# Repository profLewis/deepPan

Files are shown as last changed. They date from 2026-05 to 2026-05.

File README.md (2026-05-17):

# deepPan

3D printable tenor steel pan with section generator, note pads, and interactive sound design tools.

**Live site:** [proflewis.github.io/deepPan](https://proflewis.github.io/deepPan/)



## Project Overview

This project creates a **3D printable tenor steel pan** from a 3D scanned model. The pan is split into printable sections with individually mountable note pads, enabling replacement of damaged notes, experimentation with materials and tuning, and educational exploration of steel pan acoustics.

## Quick build (recreate the DEFINITIVE model from scratch)

The committed model in `pipeline_output/` is the **definitive build**. The
build pipeline below regenerates it byte-for-byte from `data/Tenor Pan only.obj`.

```bash
./build_from_scratch.sh         # full regenerate (~90 min)
python3 test_pipeline.py        # quick checksum check against committed manifest
python3 test_pipeline.py --full # full byte-for-byte regenerate-and-compare
```

The pipeline runs 14 stages:

1. Extract groove surfaces from source bowl
2. Solidify grooves (5 mm extrusion)
3. Generate 29 notepad meshes (no screw holes)
4. Build pan body (groove faces kept in body)
5. Extend outer-ring pad-hole boundaries
6. Thicken body to 5 mm solid
7. Generate per-pad groove-replacement ellipsoids
8. Merge body with central+inner ellipsoids
9. Voxel-remesh + pads + outer grooves + debris strip → `pan_printable.stl`
10. Split body into 7 printable pieces (truncate at Z=−122, solidify drum wall,
    build strut wedges with joinery)
11. Generate plug.stl (4 × 18 mm alignment peg)
12. Generate full bottom plate + split into 6 P1S-printable sectors
13. Generate Bambu P1S `.3mf` build plates (14 files)
14. Generate multi-object assembly view (no outer sleeves, per-pad mounts)

`pipeline_output/MANIFEST.sha256` records the SHA-256 of every committed
output; `test_pipeline.py` compares regenerated files against it (and removes
the redundant regenerated copies on a clean match).

## Printable parts and 3MF files

The full printable assembly is **14 files** ready to print on a Bambu P1S
(256 × 256 × 256 build volume):

| File | Qty | Notes |
|---|---|---|
| `pipeline_output/3mf/pan_central_half_0.3mf` and `_half_1.3mf` | 2 | Central bowl sliced in half at X=0. Each printed FLAT-CUT-FACE DOWN. 3 dowel-pin holes in tabs hanging from the bowl underside at the cut face — mated with 3 plugs from `small_parts_plugs.3mf`. Each half retains 3 of the 6 underside pegs that slot into the wedge tops. |
| `pipeline_output/3mf/pan_outer_0.3mf` … `pan_outer_5.3mf` | 6 | 60° outer sectors. Each has 2 half-wedges on its tangential edges (with horizontal-peg channels + central-peg receiver + base-screw tap holes) |
| `pipeline_output/3mf/bottom_plate_sector_0.3mf` … `_5.3mf` | 6 | Pie sectors of the bottom plate. Each has perimeter screws into the drum skirt + 2 wedge-screw clearance holes |
| `pipeline_output/3mf/small_parts_plugs.3mf` | 1 (= 12 plugs) | 12 horizontal alignment pegs — print all on one plate |

**Joinery** (no visible screw holes on the outside):

- **Adjacent outer pieces** → 2 horizontal pegs at each strut plane (R=130 + R=200), tangential axis, pushed in from the cavity side
- **Central piece** → 6 pegs baked onto its underside drop into receiver holes carved in the wedge tab tops
- **Bottom plate → wedges** → 12 M4 screws from below the plate, countersunk on the plate's underside
- **Bottom plate → drum skirt** → 8 M4 perimeter screws

## Inspecting the assembly

Open `pipeline_output/assembly_view_with_plugs.obj` in Blender — 49 separately
labelled objects (7 pan pieces + bottom plate + 12 horizontal pegs + 12 outer
mount bases + 17 central/inner push-caps). Each can be toggled on/off
independently to inspect any sub-system.

## Tenor Pan Layout

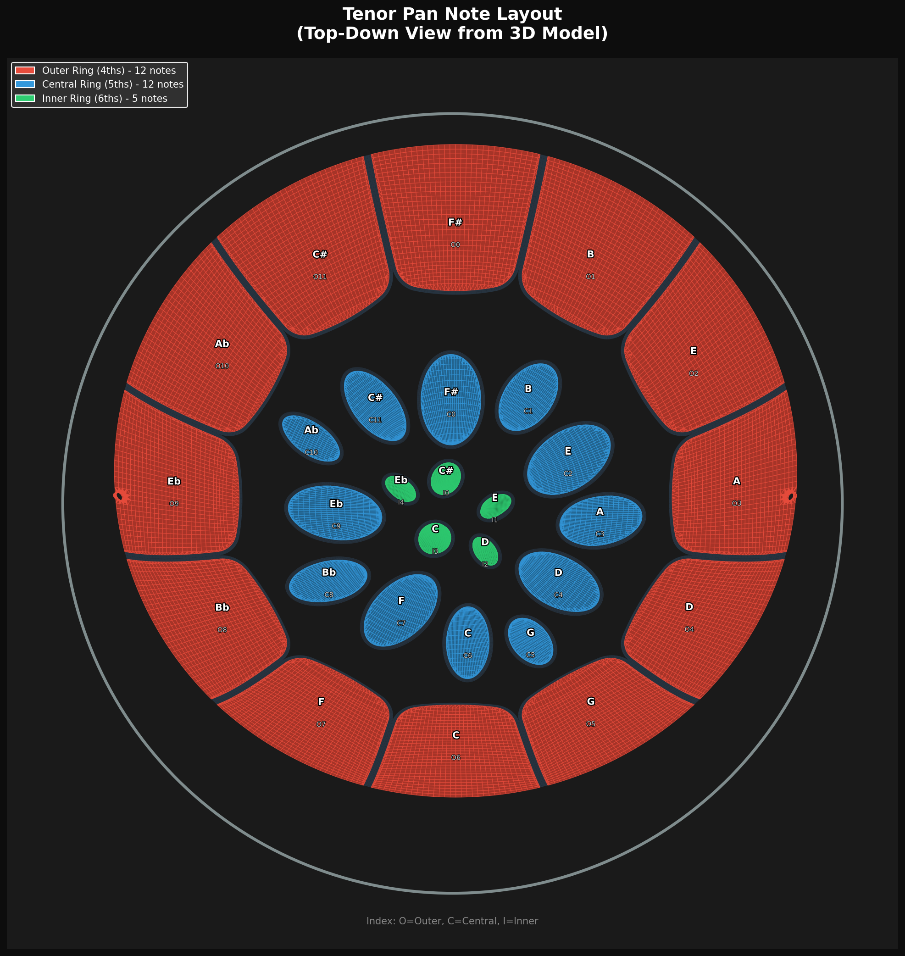
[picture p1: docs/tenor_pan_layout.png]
Tenor Pan Note Layout


The tenor pan has **29 note pads** in three concentric rings:

| Ring | Notes | Interval | Octave |
|---|---|---|---|
| Outer | 12 | 4ths | 4 |
| Central | 12 | 5ths | 5 |
| Inner | 5 | 6ths | 6 |

## Section Generator

The pan's outer ring is split into **6 printable sections** of 60° each, designed to fit a Bambu Lab P1S printer (256 x 256 x 256 mm). Each section contains 2 outer-ring notes and assembles together to reconstruct the full pan shell.

| Section | Angle | Notes |
|---|---|---|
| S0 | 15° – 75° | O2, O1 |
| S1 | 75° – 135° | O0, O11 |
| S2 | 135° – 195° | O10, O9 |
| S3 | 195° – 255° | O8, O7 |
| S4 | 255° – 315° | O6, O5 |
| S5 | 315° – 15° | O4, O3 |

Each section includes:
- **Notepad pockets** — Sunken recesses (1.5mm deep) matching each note's shape, with M4 boss through-holes for mounting
- **Profile-following support walls** — Radial walls along each cut edge whose top profile follows the drum surface, with M4 bolt holes and finger joints for alignment
- **Inner arc support** — Curved wall at R=145mm with studs and cable routing hole
- **Drum wall** — Original scanned drum geometry preserved without subdivision

```bash
# Generate all 6 sections
python generate_quarter.py --all

# Generate a single section
python generate_quarter.py S0

# View in Blender
blender --python view_all_sections.py
```

## Note Pads

Each of the 29 note pads is extracted from the 3D scan and converted into a printable solid with integrated mounting hardware:

1. **Note Pad** — Thickened to 1.5mm with a threaded mounting cylinder and 4 corner bosses
2. **Mount Base** — Screws onto the note pad, includes PCB mounting bosses (M2 holes) for electronics
3. **Outer Sleeve** — Protective housing with 12 grip ridges and cable routing

All threads use a push-fit ring groove design (2mm pitch, 1mm depth, 0.3mm clearance) optimized for FDM printing.

```bash
# Generate all 29 note pads
python generate_notepad.py --all

# Generate a specific note pad
python generate_notepad.py O5

# Generate mount hardware
python generate_mount_base.py
python generate_outer_sleeve.py
```

### 3D Printing Notes
- All meshes are watertight and manifold
- Recommended layer height: 0.2mm
- Recommended infill: 20–30%
- Support may be needed for note pad overhangs
- Thread clearance designed for FDM printers (0.3mm)

## Sound Design

The synthesizer generates realistic steel pan tones using additive synthesis with 14 adjustable parameters:

| Group | Parameters |
|---|---|
| **Envelope** | Attack, Decay, Sustain, Release |
| **Harmonics** | Fundamental, 2nd/3rd/4th Harmonic, Sub Bass |
| **Character** | Detune, Filter Cutoff, Brightness |
| **Output** | Duration, Volume |

Five built-in presets: Default, Bright, Mellow, Bell, and Pluck.

### Interactive Tools

- **[Pan Player](https://proflewis.github.io/deepPan/player.html)** — Click notes to hear them, sequence playback, 4 visualization modes
- **[Sound Designer](https://proflewis.github.io/deepPan/synth.html)** — Real-time synthesis with 14 parameter sliders and 5 presets
- **[Google Colab](https://colab.research.google.com/github/profLewis/deepPan/blob/main/deepPan_Colab.ipynb)** — Run the synthesizer in the cloud with no installation

### Command-Line Tools

```bash
# Generate all sound samples
python generate_sounds.py

# Use a preset
python generate_sounds.py --preset bright

# Play a melody
./deepPanPlay "C4 E4 G4 C5"

# Analyze a WAV file to extract parameters
python analyze_audio.py sample.wav --output params.json
```

## Pipeline Summary

| Step | Script | Output |
|---|---|---|
| Extract pan surface | `extract_pan_surface.py` | Centered bowl mesh |
| Generate note pads | `generate_notepad.py --all` | 29 note pad OBJ/STL + properties |
| Generate sections | `generate_quarter.py --all` | 6 section OBJ/STL + properties |
| Generate mount hardware | `generate_mount_base.py` | Mount base STL/OBJ |
| Generate sounds | `generate_sounds.py` | 29 WAV files |

## File Structure

```
deepPan/
├── data/
│   ├── Tenor Pan only.obj       # Source 3D model
│   ├── notepads/                # Note pad STL/OBJ + properties
│   ├── quarters/                # Section STL/OBJ + properties
│   └── mounts/                  # Mount hardware STL/OBJ
├── sounds/                      # Synthesized audio samples
├── docs/                        # Documentation images
├── extract_pan_surface.py       # Pan surface extraction
├── generate_notepad.py          # Note pad generator
├── generate_quarter.py          # Section generator (sixths)
├── generate_mount_base.py       # Mount base generator
├── generate_outer_sleeve.py     # Outer sleeve generator
├── generate_sounds.py           # Sound synthesis CLI
├── analyze_audio.py             # Audio analysis tool
├── player.html                  # Interactive pan player
├── synth.html                   # Sound design tool (browser)
├── synth_pygame.py              # Sound design tool (native Python)
├── deepPan_Colab.ipynb          # Google Colab notebook
├── deepPanPlay                  # Command-line melody player
├── view_all_sections.py         # Blender: all 6 sections
├── view_quarter.py              # Blender: single section + notepads
├── view_oriented_pan.py         # Blender: oriented pan surface
└── view_all.py                  # Blender: pan + mounts
```

## Requirements

- Python 3.x
- numpy
- scipy (for audio)

## License

This project is for educational and personal use.

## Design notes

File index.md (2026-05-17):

---
layout: default
---

## Interactive Tools

<div style="display: flex; flex-wrap: wrap; gap: 15px; margin: 20px 0;">
  <a href="player.html" style="display: inline-block; padding: 12px 24px; background: #157878; color: white; text-decoration: none; border-radius: 6px; font-weight: bold;">Play the Pan</a>
  <a href="synth.html" style="display: inline-block; padding: 12px 24px; background: #157878; color: white; text-decoration: none; border-radius: 6px; font-weight: bold;">Sound Designer</a>
  
</div>

- **[Interactive Pan Player](player.html)** -- Click notes on a steel pan to hear them. Includes sequence playback and 4 visualization modes.
- **[Sound Designer](synth.html)** -- Design steel pan sounds with real-time synthesis, 14 parameter controls, and 5 presets.
- **[Google Colab Notebook](https://colab.research.google.com/github/profLewis/deepPan/blob/main/deepPan_Colab.ipynb)** -- Run the synthesizer in the cloud with no installation.

## Project Overview

This project creates a **3D printable tenor steel pan** from a 3D scanned model. The pan is split into printable sections with individually mountable note pads, enabling replacement of damaged notes, experimentation with materials and tuning, and educational exploration of steel pan acoustics.

## Tenor Pan Layout

Tenor Pan Note Layout

The tenor pan has **29 note pads** in three concentric rings:

| Ring | Notes | Interval | Octave |
|---|---|---|---|
| Outer | 12 | 4ths | 4 |
| Central | 12 | 5ths | 5 |
| Inner | 5 | 6ths | 6 |

## Section Generator

The pan's outer ring is split into **6 printable sections** of 60° each, designed to fit a Bambu Lab P1S printer (256 x 256 x 256 mm). Each section contains 2 outer-ring notes and assembles together to reconstruct the full pan shell.

| Section | Angle | Notes |
|---|---|---|
| S0 | 15° -- 75° | O2, O1 |
| S1 | 75° -- 135° | O0, O11 |
| S2 | 135° -- 195° | O10, O9 |
| S3 | 195° -- 255° | O8, O7 |
| S4 | 255° -- 315° | O6, O5 |
| S5 | 315° -- 15° | O4, O3 |

Each section includes:
- **Notepad pockets** -- Sunken recesses (1.5mm deep) matching each note's shape, with M4 boss through-holes for mounting
- **Profile-following support walls** -- Radial walls along each cut edge whose top profile follows the drum surface, with M4 bolt holes and finger joints for alignment
- **Inner arc support** -- Curved wall at R=145mm with studs and cable routing hole
- **Drum wall** -- Original scanned drum geometry preserved without subdivision

```bash
# Generate all 6 sections
python generate_quarter.py --all

# Generate a single section
python generate_quarter.py S0

# View in Blender
blender --python view_all_sections.py
```

## Note Pads

Each of the 29 note pads is extracted from the 3D scan and converted into a printable solid with integrated mounting hardware:

1. **Note Pad** -- Thickened to 1.5mm with a threaded mounting cylinder and 4 corner bosses
2. **Mount Base** -- Screws onto the note pad, includes PCB mounting bosses (M2 holes) for electronics
3. **Outer Sleeve** -- Protective housing with 12 grip ridges and cable routing

All threads use a push-fit ring groove design (2mm pitch, 1mm depth, 0.3mm clearance) optimized for FDM printing.

```bash
# Generate all 29 note pads
python generate_notepad.py --all

# Generate a specific note pad
python generate_notepad.py O5
```

## Sound Design

The synthesizer generates realistic steel pan tones using additive synthesis with 14 adjustable parameters:

| Group | Parameters |
|---|---|
| **Envelope** | Attack, Decay, Sustain, Release |
| **Harmonics** | Fundamental, 2nd/3rd/4th Harmonic, Sub Bass |
| **Character** | Detune, Filter Cutoff, Brightness |
| **Output** | Duration, Volume |

Five built-in presets: Default, Bright, Mellow, Bell, and Pluck.

## Command-Line Tools

```bash
# Generate all sound samples
python generate_sounds.py

# Use a preset
python generate_sounds.py --preset bright

# Play a melody
./deepPanPlay "C4 E4 G4 C5"

# Analyze a WAV file to extract parameters
python analyze_audio.py sample.wav --output params.json
```

## Pipeline Summary

| Step | Script | Output |
|---|---|---|
| Extract pan surface | `extract_pan_surface.py` | Centered bowl mesh |
| Generate note pads | `generate_notepad.py --all` | 29 note pad OBJ/STL + properties |
| Generate sections | `generate_quarter.py --all` | 6 section OBJ/STL + properties |

## Source

View the full source and documentation on [GitHub](https://github.com/profLewis/deepPan).

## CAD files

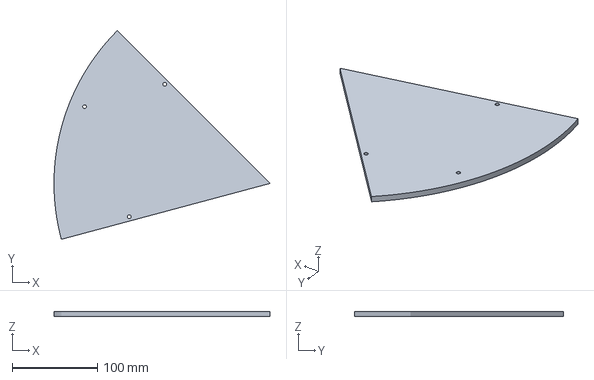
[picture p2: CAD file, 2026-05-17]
pipeline_output/3mf/bottom_plate_sector_2.3mf
254.0 x 245.3 x 6.00 mm

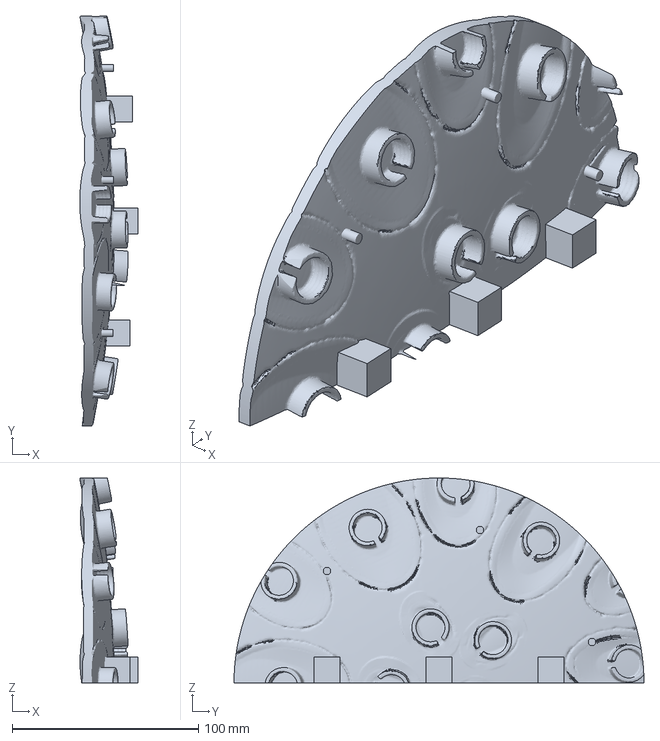
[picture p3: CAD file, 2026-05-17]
pipeline_output/3mf/pan_central_half_0.3mf
31.4 x 220.0 x 110.0 mm

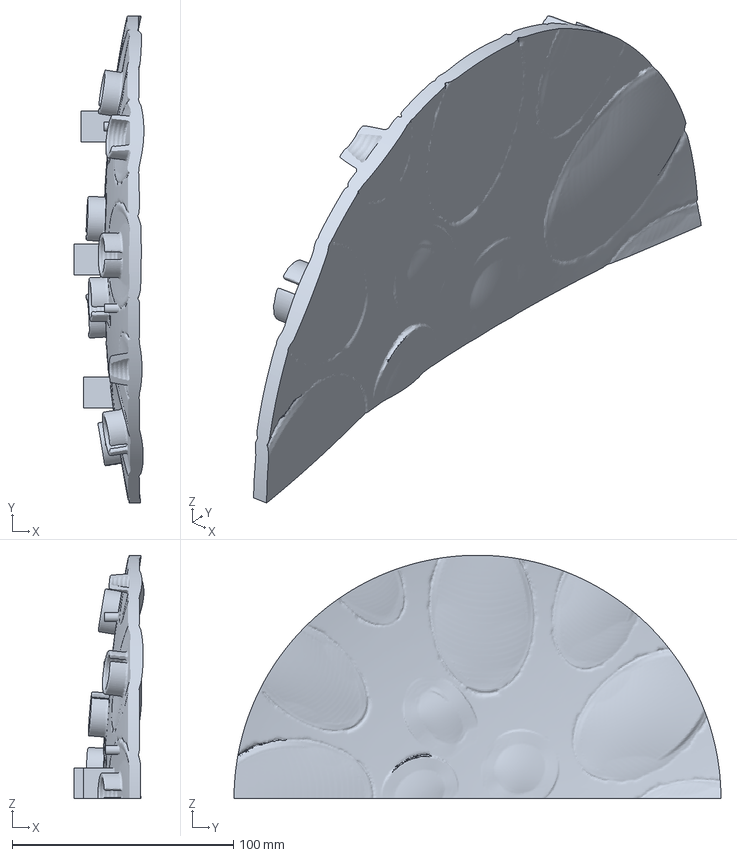
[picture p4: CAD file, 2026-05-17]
pipeline_output/3mf/pan_central_half_1.3mf
31.5 x 220.0 x 110.0 mm

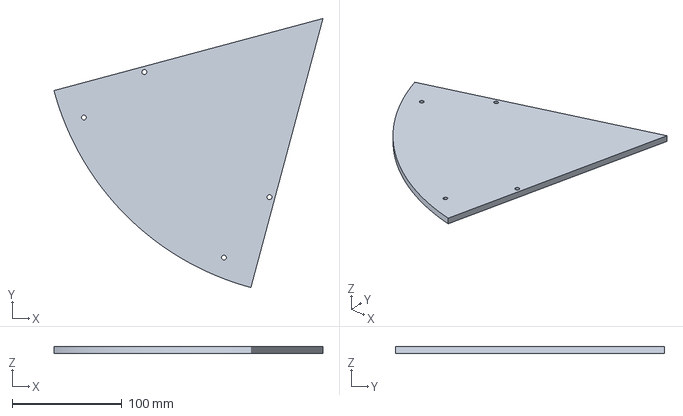
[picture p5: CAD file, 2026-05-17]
pipeline_output/3mf/bottom_plate_sector_3.3mf
245.3 x 245.3 x 6.00 mm

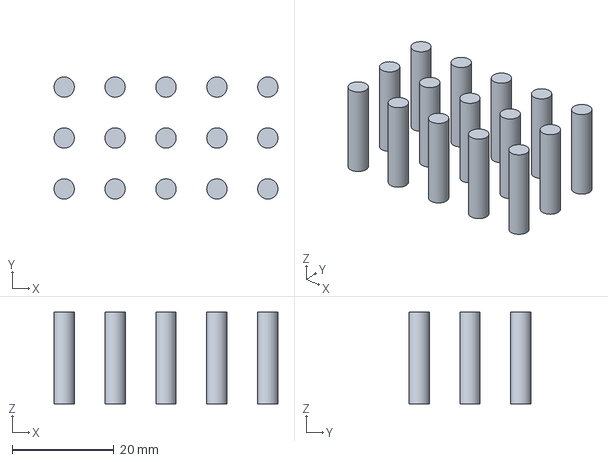
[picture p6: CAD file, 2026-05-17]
pipeline_output/3mf/small_parts_plugs.3mf
44.0 x 24.0 x 18.0 mm

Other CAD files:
pipeline_output/3mf/bottom_plate_sector_4.3mf
pipeline_output/3mf/bottom_plate_sector_1.3mf
pipeline_output/3mf/bottom_plate_sector_5.3mf
pipeline_output/3mf/bottom_plate_sector_0.3mf

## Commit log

2026-03-26 Fresh start: scripts only, no LFS
    [Tenor Pan only.obj]
2026-03-26 Add M2/M3 flat-head countersink to all screw holes
    - Phase 8: pad screw pilot holes now include 90° countersink cone
    at pocket floor (4.0mm dia, 1.0mm deep, DIN 965 M2)
    - Base plate clearance holes now include 90° countersink cone
    on bottom face (6.0mm dia, 1.3mm deep, DIN 965 M3)
    [Tenor Pan only.obj]
2026-03-26 Update all scripts with latest features
    - Tapered countersink, screw cap, boss internal threads
    - Inner pad flange extension (7mm min), opposite-end hole placement
    - Outer pad cloning from O0, pad shrink for groove fit
    - Groove protrusion wired to flange thickening
2026-03-26 Track source OBJ with git LFS
    Only 'data/Tenor Pan only.obj' uses LFS — all other generated
    OBJ/STL files are in .gitignore and regenerated locally.
2026-03-26 Symmetric masks, countersink holes, groove generation, pad regeneration
    - Hardware masks symmetric about pad PCA long axis for PCB clearance
    - M2 countersink (4mm, 1mm deep) at pad pilot holes in drum body
    - M3 countersink (6mm, 1.3mm deep) at base plate clearance holes
    - Separate OBJ/STL for drum body and base plate
    - generate_grooves.py: tapered grooves per ring, 0.25mm raised
    - generate_maps.py: shows symmetric masks + groove boundaries
    - STEP_INNER=0.1mm, groove pad tolerance=0.5mm
    - All 29 pads regenerated with updated parameters
2026-03-26 Cap inner pad scaling at 1.15x to prevent overlap, regenerate assembly
    Inner pads I1/I2/I4 were scaling up to 1.19x causing overlap.
    Now capped at MAX_INNER_SCALE=1.15. Assembly view, maps, and grooves
    all regenerated with updated geometry.
2026-03-26 Fix inner pad overlap: reduce flange extension, reconcile map boundaries
    - Reduced inner pad flange extension from 7mm to 4mm minimum to prevent
    overlap between adjacent inner pads (I0/I4 and I1/I2 were overlapping)
    - Maps now use assembly_view Pad_* convex hull as boundary (matches
    actual solid footprint) instead of raw pad surface edge
    - Verified zero overlap between all inner pad pairs
2026-03-26 Relax inner pad screw hole constraints (1.5mm from edge/hw, was 2.0mm)
    Previous values (backup): MIN_EDGE_DIST=2.0, MIN_HW_DIST=2.0
    New values: MIN_EDGE_DIST=1.5, MIN_HW_DIST=1.5
    This gives more candidate positions on the compact inner pad flanges.
2026-03-26 Attach grooves to central pads, shift inner boss positions inward
    - Central pads: groove thickened and combined with pad solid, giving
    screw holes material beyond the pad edge. Edge distance relaxed to
    2.0mm (groove provides support).
    - Inner/central pads: boss auto-shifts inward when too close to pad
    boundary (I4 shifted 3.4mm, all inner pads adjusted).
    - All 12 central pads: 4 holes each, all 5 inner pads: 2 holes each.
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2026-03-26 Symmetric hardware mask filtering for all screw holes across all rings
    - Compute actual symmetric hardware mask (cylinder hull mirrored about
    pad long axis, buffered) for every pad — matches yellow zones on maps
    - Inner/central pads: screw hole candidates rejected if inside mask polygon
    - Outer pads: compute_hole_positions now accepts hw_mask_2d parameter,
    rejects candidates in hardware zone instead of using circular clearance
    - I4 flange extension increased to 5mm for better screw hole placement
    - No screw holes land in void/hardware areas on any pad
2026-03-26 Post-validate screw holes against actual assembly hardware masks
    Added validation pass after assembly_view generation that checks every
    screw hole against the real symmetric hardware mask (MountBase + Sleeve
    from assembly_view.obj). Removed 24 holes that were inside hardware
    zones. Zero violations remain.
    Hole counts after validation:
    - Outer: O0/O3/O6/O9=4, others=2
    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
2026-03-26 Add generate_pins.py: M2 flat-head alignment pins for all screw holes
    Generates 82 printable pins (one per screw hole) with tapered DIN 965
    cone head (3.8mm→2.0mm, 0.9mm) and 15mm shaft. Total length ~16mm.
    Output: data/notepads/pins.obj in body coords.
2026-03-26 Add 2mm plug bore above countersink for flush cap, update pins to match
    Screw hole profile (top to bottom):
    - 2mm cylindrical plug bore at head diameter (4.0mm) for flush cap
    - 1mm tapered countersink (4.0mm → 2.2mm, 90° DIN 965)
    - Shaft clearance hole (2.2mm) through remainder
    Updated in: pad boolean subtraction (generate_notepad.py),
    drum body voxel holes (generate_pan_body.py), and pins (generate_pins.py).
    Pin profile: 2mm plug + 0.9mm taper + 13.1mm shaft = 16mm total.
    Screw cap updated to fill plug bore + taper recess.
2026-03-26 Fix inner pad pin clearance, clone O3 from O2 and O9 from O8
    - Inner pad flange extension increased to 6mm (I4: 6.5mm)
    - MIN_EDGE_DIST for inner pads increased to 2.2mm (pin head 1.9mm + margin)
    - All inner pad holes now have ≥0.3mm pin head margin (was overhanging)
    - O3 cloned from O2, O9 cloned from O8 (internal geometry issues)
    - Pins regenerated with plug+taper+shaft profile (82 pins, 16mm)
2026-03-26 Fix outer pad cloning (Y-axis rotation), I0 nudge, inner pad clearance
    - Outer pad clones (O3 from O2, O9 from O8) now use simple Y-axis
    rotation matching angular position on drum — preserves bowl curvature
    exactly, no bbox distortion
    - I0 nudged -5° around inner ring centroid to clear I4 overlap
    - Inner pad flange extended to 6mm (I4: 6.5mm)
    - Inner pad MIN_EDGE_DIST=2.2mm (pin head 1.9mm + margin)
    - All pin heads clear of pad edges by ≥0.3mm
2026-03-26 Fix outer clone: rotate around actual drum axis (not Y axis)
    The drum axis in source coords is tilted (~17° from Y toward Z).
    Rotation now uses the true drum axis computed via R_level^T @ [0,1,0].
    Angular analysis confirms all 12 outer pads at ~30° spacing.
    O2→O3 = 31.9°, O8→O9 = 28.1°.
2026-03-26 Snap outer pad clone rotation to 30° multiples
    O2→O3 and O8→O9 now rotate exactly 30° around drum axis.
2026-03-26 Increase I0 nudge to -7° for 1.2mm gap from I4
    Properties (centroid, normal) are computed after nudge, so
    assembly_view hardware placement is automatically correct.
2026-03-26 Add needle extraction hole to pin heads
    Each pin now has a small 0.8mm radial through-hole near the top of the
    plug section (at Z=-0.5mm) so a needle or wire can hook the pin for
    removal. Uses trimesh boolean subtraction with graceful fallback.
2026-03-26 Fix inner ring pin holes: init per-pad state, relaxed fallback search
    - Initialize _inner_extended_ring, _flange_solid_v, _groove_attached at
    start of each pad generation to prevent stale data from previous pads
    - Replace fragile 'in dir()' checks with proper None checks
    - Add relaxed constraint retry when inner ring candidate search yields
    fewer than 2 holes (reduces MIN_EDGE_DIST from 2.2mm to 1.5mm)
    - Fixes I4 getting only 1 screw hole instead of 2
2026-03-26 Attach grooves to all pads (outer + inner rings)
    - Outer ring: thicken groove and combine with pad solid (same as central)
    - Inner ring: thicken pad first, then attach groove, plus flange extension
    - All three rings now produce pad-groove combination meshes
2026-03-26 Clone all outer pads from O1 by 30-degree rotation
    - Update clone_map: all outer pads (O0, O2-O11) now clone from O1
    - Uses existing drum-axis rotation with 30-degree snapping
    - Adds 0.3mm groove edge shaving on cloned grooves for printing tolerance
    - O1 remains the template pad generated from source geometry
2026-03-26 Fix missing pins: retry hole placement with reduced separation
    When the greedy hole selection can't find enough holes (e.g. 4 requested
    but only 2 found), retry with progressively reduced min_hole_sep (6mm,
    then 4mm). This ensures pads get the full SCREW_HOLE_COUNT of holes
    even when the hardware mask leaves a tight available area.
2026-03-26 Add bounding cylinders, PCB prototype, integrate into assembly view
    - generate_central_mount.py: add generate_pcb_prototype() (20x20mm board
    with M2 pins on 16mm grid) and generate_bounding_cylinder() (vertical
    cylinder tightly fitting around push-cap mechanism with tolerance)
    - generate_assembly_view.py: include BoundingCylinder_XX and PCBPrototype_XX
    objects for central/inner pads in assembly_view.obj
    - Write separate bounding_cylinders.obj for use in pan body carving
2026-03-26 Add structural cylinders, assembly carving, and region extraction
    Tasks 9-12 implemented:
    - generate_cylinders.py: parameters for inner (250mm OD, 10mm wall) and
    outer (271mm OD, 10mm wall) structural cylinders with key/slot and
    30mm wiring hole
    - generate_pan_body.py Phase 6b-6f: embed inner/outer cylinders in voxel
    grid, clipped at drum surface; add key/slot alignment; cut wiring hole;
    add cylinder screw holes and base plate clearance holes
    - Phase 7b: carve bounding cylinder cavities for push-cap mechanisms
    - Phase 10a-d: extract inner cylinder, outer cylinder, body, and base
    plate as separate meshes via marching cubes
    - Phase 12: export all components as named OBJ objects and s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
2026-03-26 Use all_hole_positions for pin generation
    Pin generator now uses all_hole_positions (pre-validation set) when
    available, ensuring every physical hole in the pad gets a corresponding
    pin. This fixes missing pins for pads where hardware mask validation
    removes some holes from the pilot-hole carving list.
    I4 now gets 2 pins, all outer pads get 4 pins. Total: 106 pins.
2026-03-26 Fix math import and optimize cylinder voxel filling
    - Add math to top-level imports (was only imported locally in Phase 8)
    - Use numpy slice assignment instead of per-voxel python loop for
    cylinder filling (Phase 6b/6c)
    - Optimize wiring hole carving with Y-range and angular narrowing
2026-03-27 Replace dual cylinders with single cylinder + 6 radial struts
    Redesign structural support from inner/outer cylinder pair to:
    - Single cylinder R=115-135mm, split at R=125mm for assembly
    - 6 radial struts (20mm thick) at section boundaries (15/75/135/195/255/315 deg)
    - 7-piece assembly: 1 central piece (R<125) + 6 identical outer pieces
    - Full-height radial key/slot at R=125 (10mm wide, 2.5mm deep)
    - Full-height side key/slot on strut edges for outer piece interlocking
    - 30mm wiring holes in each strut + 6 around cylinder between struts
    - M3 screw holes within 5mm of all edges
2026-03-27 Add extract_pieces.py for two-stage grid-then-SDF workflow
    Instead of running SDF marching cubes on the full grid (which exceeds
    RAM at 0.2mm resolution), the workflow is now:
    1. generate_pan_body.py --grid-only --res=0.2
    Builds voxels, carves features, assigns pieces, saves .npz
    2. extract_pieces.py --grid=data/pan_body_0.2mm_grid.npz
    Loads .npz, crops each piece to its bounding box, runs SDF on
    the cropped volume, exports OBJ+STL
    Key optimization: bounding-box cropping means each SDF runs on ~10-30%
    of the full grid volume, fitting comfortably in RAM.
    Also adds --grid-only flag to generate_pan_body.py to skip extraction,
    and saves iy_base_top_cyl to the .npz for piec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
2026-03-27 Cut rim inner edge at outer-pad top Y level
    Rounded rim edge faces that dip below the outer pad top (Y=53.1mm) are
    excluded so the rim doesn't interfere with pad pockets and hardware holes.
    Steep-normal wall faces (the cylindrical skirt) are kept at all Y values.
    6,210 faces (was 17,179) — clean inner boundary, full outer wall.
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2026-03-27 Clip voxel body at rim boundary (R=244mm)
    The voxel body now stops at the outer pad top inner radius (R=244mm).
    The rim mesh (from extract_rim.py) covers R > 244mm. This prevents
    the voxelized body from duplicating the drum wall that the rim provides.
    Fill boundary: R <= min(surface_R, 244mm). Body dropped 22M voxels
    (was 24M — drum wall at R > 244 removed).
2026-03-27 Integrate rim mesh into voxel body (thickened inward)
    Phase 5a loads the rim mesh (drum_rim.obj), thickens each triangle 5mm
    inward toward the drum center, and fills those voxels into the grid.
    This happens BEFORE pad pockets (5b) and hardware holes (7), so those
    features carve through the rim too.
    Reverts the R=244 clip — the full drum surface boundary is used again
    since the rim is now part of the voxel body, not a separate shell.
    718K rim voxels added at 1mm resolution from 16K triangles.
2026-03-27 Integrate rim into voxel body + add assembly view STL export
    generate_pan_body.py:
    - Revert R=244 clip (rim is now part of the voxel body)
    - Phase 5a voxelizes the rim mesh (drum_rim.obj) thickened 5mm inward
    - Pad pockets (5b) and hardware holes (7) carve through the rim too
    generate_assembly_view.py:
    - Add STL export (assembly_view.stl) alongside the OBJ
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2026-03-27 Replace per-triangle rim voxelization with smooth radial heightmap
    The cylindrical drum wall was bumpy because per-triangle voxelization
    creates staircase artifacts on curved surfaces. Now builds a 2D radial
    heightmap R_surface(theta, Y) from rim mesh vertices (720 angle bins),
    smoothed with uniform filter. Each voxel is filled if its radius falls
    within [R_surface - thickness, R_surface], producing a smooth cylinder.
2026-03-27 Extend rim wall from body boundary to surface (thick solid wall)
    The 5mm fixed thickness left a gap between the body fill (R=244) and
    the rim wall (R=surface-5). Now the rim fills from R=rim_clip_r-1 (243mm)
    all the way to R_surface, creating a solid wall that seamlessly connects
    to the body. Wall is 7-15mm thick depending on angle.
    504K rim voxels at 1mm (was 318K with 5mm shell).
2026-03-27 Fix drum wall: force rim_y height for R > DRUM_WALL_RADIUS
    The heightmap interpolation gave garbage values at R=245-255 (boundary
    of playing surface data), creating holes in the drum wall. Now all
    columns at R > 225mm (DRUM_WALL_RADIUS) are forced to rim_y height
    regardless of interpolation. Phase 5a trims the top to the actual
    curved rim profile. Phase 7 skips R > rim_clip_r to preserve wall.
    Wall columns now have ~160 voxels (was 7) — solid from base to rim.
2026-03-27 Fix wall region + add final pad/hardware cleanup pass
    - Wall fill forced to rim_y only at R > rim_clip_r (244mm), not R > 225mm.
    This preserves the playing surface heightmap for the pad area (R=225-244).
    - Phase 8c: final cleanup re-carves ALL pad pockets and hardware holes
    after all structural additions, removing any protrusions from wall/strut
    material that bled into pad cavities. Cleaned 77K extra voxels at 1mm.
    - Phase 7 still preserves wall at R > rim_clip_r during initial hw carving.
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2026-03-28 Fix double-carving: merge 8c+8d into single consistent cleanup pass
    The old Phase 8c re-carved hardware holes WITHOUT wall preservation
    (punching through the drum wall), and Phase 8d eroded the FULL 3D
    volume of assembly objects (removing structural material below pads).
    Now a single Phase 8c:
    - Pad pockets: pocket_floor to pad_y_top (correct depth, not full volume)
    - Hardware holes: base_top upward, R <= rim_clip_r (wall preserved)
    Cleanup dropped from 77K+1.6M to 12K voxels at 1mm — the earlier
    phases now do their job correctly without needing aggressive re-carving.
2026-03-30 Fix screw distances, remove double-carve, add --no-pads mode
    1. Screw edges +1mm: INSET 7->8, inner 4->5, central 5->6/5, HW dist +1
    2. Phase 8c (redundant re-carve causing double-gouge on central pads) REMOVED
    - Phase 5b already carves correctly with max(pad_top, col_top)
    - Phase 8c used only pad_top, creating a second step at different height
    3. --no-pads flag: skips Phase 5b (pockets), 5c (grooves), 8 (pad screws)
    for structure-only model generation
2026-03-30 Fix groove print indentation under no_pads else block
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2026-03-31 Add --y-factor for anisotropic Y resolution + anisotropic SDF support
    generate_pan_body.py: --y-factor=N multiplies Y grid resolution by N
    (e.g. --y-factor=4 gives 0.025mm Y at 0.1mm XZ). Y range uses res/N.
    extract_pieces.py: auto-detects anisotropic spacing from stored ranges.
    SDF distance_transform_edt uses sampling= parameter for correct
    anisotropic distances. Marching cubes uses (sx,sy,sz) spacing.
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2026-03-31 Remove rim_clip_r constraint — natural heightmap boundary
    The rim_clip_r (R=244mm) constraint was forcing rim_y height for the
    drum wall region, which cut through outer pads and created ragged edges.
    Removed:
    - wall_region override (forced rim_y at R > 244)
    - Phase 5a rim trim (trimmed at rim profile for R > 244)
    - Phase 7 R > rim_clip_r skip (blocked hardware holes in wall)
    Now the heightmap interpolation + surface_r_map define the boundary
    naturally. NaN columns (beyond interpolation) still default to rim_y.
    The SDF smoothing handles the surface quality.
2026-04-01 Push cap solid cylinder, M2 through-holes, inner pad fixes, pantry deformation
    - Push cap: solid trimesh cylinder with boolean-subtracted pizza-slice slit
    and proper internal walls. M2 holes drilled through plate via trimesh
    boolean on a proper volume mesh.
    - Mount base: M2 through-holes via voxelize+drill pipeline
    - Inner pads: removed groove attachment, fixed flange thickness (uniform
    normal), fixed screw holes through flange, fixed pan body pocket depth
    using local column heightmap
    - Bounding ellipse prism replaces bounding cylinder
    - PCB prototype: correct orientation, through-holes, longer pins
    - Screw hole countersinks fixed to top side (fallback extrusion path)
    - New scripts: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
2026-04-01 Add thicken_mesh.py: pure mesh offset, no voxels
    Offsets pantry.stl vertices 10mm along inward normals to create a
    closed shell. Outer surface = exact original mesh. Inner surface =
    offset copy with reversed winding. 647K triangles, instant.
2026-04-01 Only thicken into drum: skip base vertices (normal Y < -0.3)
    Base faces (downward-pointing normals) are not offset, so the base
    stays flat and no material is added outward. Only the playing surface
    and drum wall get 10mm inward thickening.
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2026-04-01 Fix thickening: trust STL outward normals, no flip, no clip
    STL face normals are outward by convention. Offset = verts - thickness * normals
    goes inward into the drum. The previous flip (avg_ny < 0) reversed everything.
2026-04-01 Add carve_pads.py: per-pad high-res carving from pantry_thick
    For each pad/mount/sleeve in assembly_view.obj, creates a LOCAL 0.1mm
    voxel grid around that pad's bounding box, voxelizes both the pantry
    and the pad, subtracts, and SDF-extracts the carved region. Replaces
    the pantry triangles in that box with the carved mesh. Writes
    intermediate STL after each pad for inspection.
2026-04-01 Increase pad carving margin from 0.2mm to 5mm
    The tight 2*res margin missed pantry mesh around the pad edges.
    Now uses 5mm margin to fully capture surrounding geometry.
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2026-05-15 Restructure pipeline: ellipsoid groove replacement + printable build
    New pipeline (build_from_scratch.sh runs end-to-end from
    data/Tenor Pan only.obj to pipeline_output/pan_printable.stl):
    generate_grooves.py
    solidify_grooves.py
    generate_notepad.py --all (each outer pad now generated
    independently — no rotation clone)
    generate_pan_holes.py (groove faces kept in body)
    extend_pan_holes.py (1mm tangent + Laplacian falloff,
    outer ring only)
    thicken_blender.py --offset=1.0 (corrected — was thickening upward)
    make_groove_ellipsoids.py (SVD-oriented per-pad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
2026-05-16 Add assembly hardware: strut tabs, dowel pins, locking ring, bottom plate
    Pipeline now produces a fully assembleable 7-piece pan with all-M4 hardware
    hidden from the playing surface.
    generate_bottom_plate.py — flat plate at drum-skirt base with 8 M4
    countersunk holes. Fixed axis bug: STL is Z-up (Blender convention),
    not Y-up; plate now correctly oriented with axis along Z.
    add_assembly_holes.py — drills/embeds three hardware families into
    pan_printable.stl before splitting:
    (A) STRUT JOINTS — 18 internal reinforcement TABS (3 per strut plane
    × 6 planes) overlapping the inside of the skirt wall (R 234..246).
    Tab straddles each strut c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
2026-05-17 Definitive printable model: drum-flush base, solid drum wall, 14 P1S .3mf plates
    Locks in the definitive deepPan build:
    * Body bottom truncated at Z=-122 so the drum has a clean flat plane that
    the base plate mates against (no protrusion gap).
    * Drum wall UNION'd with a solid annular ring (R=240..246, Z=-122..+50),
    closing any internal voids.
    * Strut wedges curve to follow the actual bowl underside (ray-cast from
    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
    [bottom_plate_sector_0.3mf, bottom_plate_sector_1.3mf, bottom_plate_sector_2.3mf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]
2026-05-17 Fix 3MF reproducibility check: hash inner model contents, not raw zip
    3MF files are zip archives that embed creation timestamps + random UUIDs
    in their metadata XML, so the raw zip's SHA-256 changes every build even
    when the actual mesh content is identical. The reproducibility test was
    flagging all 14 .3mf files as "different" purely because of these
    timestamps; the underlying STL geometry was byte-identical.
    test_pipeline.py now extracts each 3MF's 3D/<name>.model files and hashes
    THOSE — which is what we actually care about reproducing.
    MANIFEST.sha256 rebuilt with the new content-based hashes for 3MFs.
    All 16 STLs and 14 3MFs now match the committed reference.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
2026-05-17 Tidy: move legacy scripts to old/
    Moved 21 unused / superseded scripts out of the top level:
    add_assembly_holes.py, build_assembly_features.py, check_holes.py,
    decimate.py, generate_assembly_view{,_full}.py, generate_cylinders.py,
    generate_diagram.py, generate_interactive.py, generate_maps.py,
    generate_pin_and_ring.py, generate_pins.py, generate_screw_cylinders.py,
    generate_small_mount_base.py, generate_small_outer_sleeve.py,
    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
    [pan_central.3mf]
2026-05-17 Slice central piece into 2 semicircles with dowel-pin joinery
    The central bowl piece is now split at X=0 into two half-disc pieces, each
    with 3 tabs hanging from the bowl underside at the cut face (Y = -60, 0, +60).
    Each tab has a 4.2 mm horizontal channel for the slip-fit alignment plug
    (same 4 × 18 mm plug.stl reused from the strut joinery — pin count 12 → 15).
    Pin Z positions follow the bowl-underside curve: -47.2, -51.5, -48.4 mm so
    the tabs hang at the correct height where the shell exists.
    The 3MFs for the halves are oriented with their FLAT CUT FACE on the build
    plate (rotate ±90° around Y), so the bowl arc points UP — bbox 31 × 220 × 110
    mm, fits Bambu P1S comfortably.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
    [bottom_plate_sector_0.3mf, bottom_plate_sector_1.3mf, bottom_plate_sector_2.3mf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]
2026-05-17 Fix another orphaned import: generate_maps in screw-hole validation
    generate_notepad.py uses generate_maps.{compute_symmetric_hw_mask,
    load_assembly_view} for a post-validation step that removes screw holes
    overlapping the symmetric hardware mask. We're building with
    --no-screw-holes, so this step is a no-op anyway. Made the import
    optional via try/except — earlier returns gracefully if generate_maps
    (moved to old/) is unavailable.
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
